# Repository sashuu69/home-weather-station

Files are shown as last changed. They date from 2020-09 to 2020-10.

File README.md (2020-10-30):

# Home Weather Station

## Introduction

The home Weather Station is a DIY weather Station that collects the following data and uploads the data to firebase:-

1. Air Quality Index
2. Compressed Natural Gas (CNG)
3. Liquid Petroleum Gas (LPG)
4. Smoke
5. Rain
6. Temperature
7. Humidity
8. Heat Index

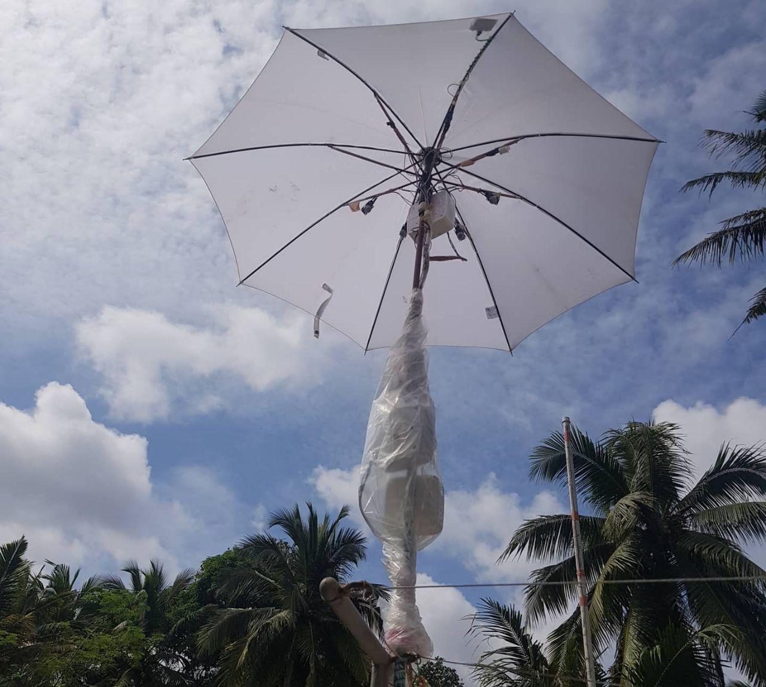
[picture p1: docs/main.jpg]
<br>

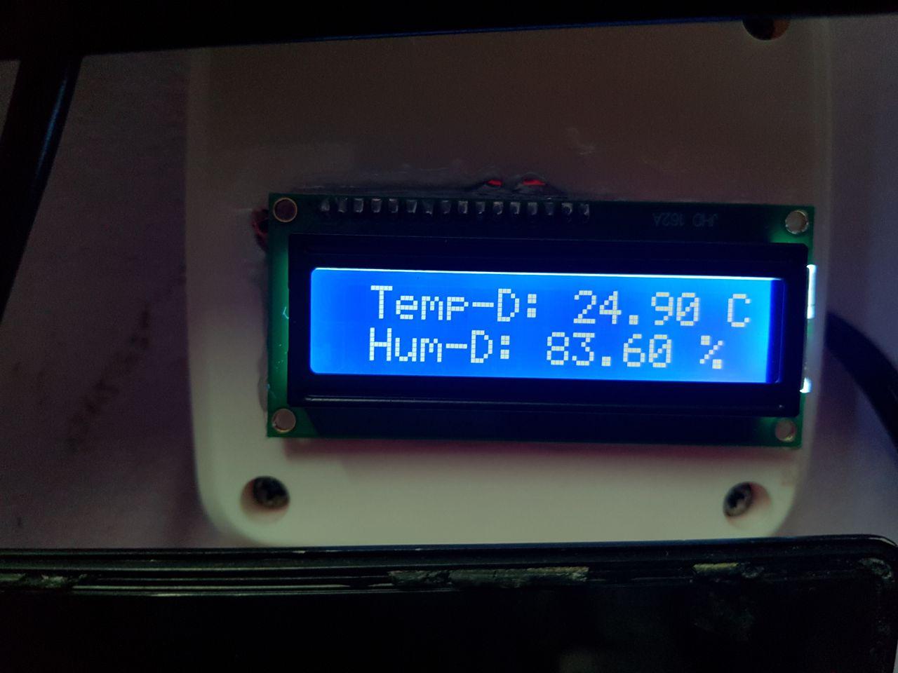
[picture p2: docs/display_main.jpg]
<br>

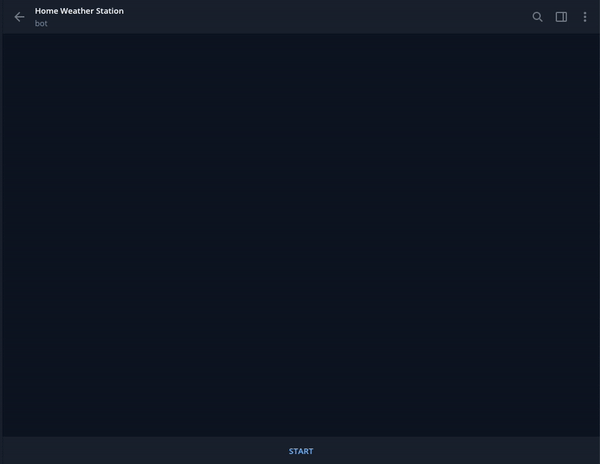
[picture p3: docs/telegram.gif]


## Features

1. Collects AQI, CNG, LPG, smoke, temperature, humidty, rain presence and heat index. The values from gas sensors are converted to PPM. Thank you for [Bharath Kinnera](https://www.youtube.com/channel/UCRqjLSpVN0EyjDmoq2dKJwg) for this [Gas sensor PPM conversion video](https://www.youtube.com/watch?v=w5kyyQCsyfQ).
2. Stores the data in a log file and Firebase.
3. Dispays the data in a LCD display.
4. A telegram bot for fetching values.

## Folder Structure

1. arduino_nano_code: Contains the embedded C code for flashing to the arduino nano board.
2. arduino_uno_code: Contains the embedded C code for flashing to the arduino uno board.
3. docs: Contains images of the product.
4. heroku_code/telegram-bot: Telegram bot python code for Heroku server.
    1. telebot
        1. __init__.py: Library initialisation.
    2. app.py: Main program for telegram bot.
    3. Procfile: Procfile is for Heruku.
    4. requirements.txt: Library names required for running telegram bot program.
5. pi_code: Contains the code to be run on the Raspberry Pi Zero W.
    1. dataRetriver.py: Python program that gets values from sensor and stores the data in log file and firebase.
    2. lcdDisplay.py: Python program to display data on LCD screen.
    3. requirements.txt: Required libraries for the python programs in this folder.
    4. RPi_I2C_driver.py: LCD display driver.
    5. sampleENV: A sample env that lists all the env variables used by the programs.

## Components Used

1. Arduino Nano - [Tomson Electronics](https://www.tomsonelectronics.com/products/buy-arduino-nano-v3-0-online-india)
2. Arduino UNO and programming cable - [Tomson Electronics](https://www.tomsonelectronics.com/products/arduino-bundle-1)
3. MQ-2 gas sensor - [Tomson Electronics](https://www.tomsonelectronics.com/products/mq-2-mq2-smoke-gas)
4. MQ-4 - [Amazon](https://www.amazon.in/REES52-Natural-Methane-Sensor-Arduino/dp/B01L0FIH94)
5. MQ-5 - [Tomson Electronics](https://www.tomsonelectronics.com/products/smoke-gas-detector-sensor-module)
6. MQ-135 - [Tomson Electronics](https://www.tomsonelectronics.com/products/air-quality-control-gas-sensor-mq-135)
7. Rain sensor - [Tomson Electronics](https://www.tomsonelectronics.com/products/rain-drop-detection-sensor-rain-detector-weather-module)
8. DHT22 - [Tomson Electronics](https://www.tomsonelectronics.com/products/dht22-digital-temperature-and-humidity-sensor-module-am2302)
9. Raspberry Pi Zero W - [Tomson Electronics](https://www.tomsonelectronics.com/products/buy-raspberry-pi-zero-w-online-india)
10. LCD module - [Tomson Electronics](https://www.tomsonelectronics.com/products/16x2-jhd-lcd-display)
11. LCD I2C module - [Tomson Electronics](https://www.tomsonelectronics.com/products/iic-i2c-serial-interface-adapter-module-for-display)
12. SD card class 10 16 GB - [Amazon](https://www.amazon.in/HP-MicroSD-U1-TF-Card-16GB/dp/B07DJGJ2H1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)
13. 220V to 12V DC Adapter - [Amazon](https://www.amazon.in/TRP-TRADERS-CAMCALL-Power-Adapter/dp/B01FTYAUCY)
14. Buck converter - [Tomson Electronics](https://www.tomsonelectronics.com/products/lm-2596-dc-dc-buck-converter)
15. Male headers - [Tomson Electronics](https://www.tomsonelectronics.com/products/40x2-male-berg-strip-straight)
16. Female headers - [Tomson Electronics](https://www.tomsonelectronics.com/products/40x2-female-berg-strip-straight)
17. Dotted PCB - [Robo Elements](https://www.roboelements.com/product/general-purpose-zero-pcb-printed-circuit-board-4x6-inches/)
18. Ribbon cable - [Amazon](https://www.amazon.in/Ribbon-Cable-10-wire-15ft/dp/B007R9SQQM)
19. USB extension cable - [Amazon](https://www.amazon.com/Monoprice-Extension-Repeater-PlayStation-Keyboard/dp/B004PLLA9U?th=1)
20. Powered USB hub - [Amazon](https://www.amazon.in/Protronix-Port-USB-Power-Adapter/dp/B00REX6DRK)
21. Pole, Umbrella, wires, tapes and zip ties

Discount code for Tomson Electronics : ZENOOFF2020

## Pre-Installation Steps

1. Connect the sensors as per circuit diagram.
2. Flash the nano and uno code respectively.
3. Clone the project in Raspberry Pi Zero W.
4. Rename sampleENV as .env.
5. Create Realtime database in firebase.
6. add the necessary edits to .env file
7. Run the python programs inside pi_code folder.
8. create a python inside heroku_code/telegram-bot with name credentials.py with following contents:-

    ```python
    bot_token = "Bot Token"
    bot_user_name = "Bot Username"
    URL = "Heroku app URL"
    firebase_token = "Firebase token"
    firebase_authDomain = "Firebase authDomain"
    firebase_databaseURL = "Firebase database URL"
    firebase_storageBucket = "Firebase Storage Bucket"
    ```

## Images

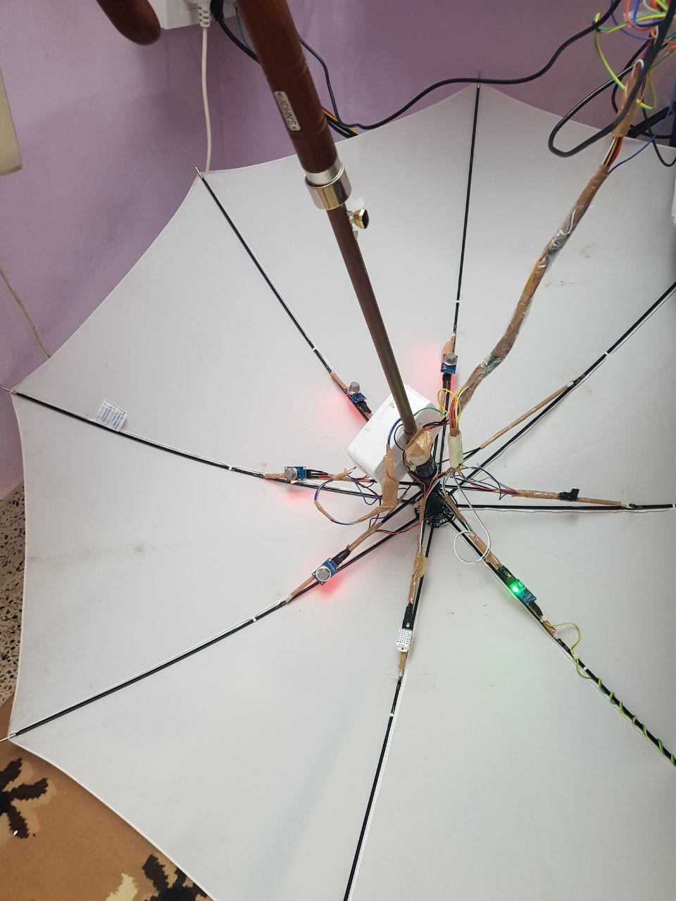
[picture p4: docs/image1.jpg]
<br>

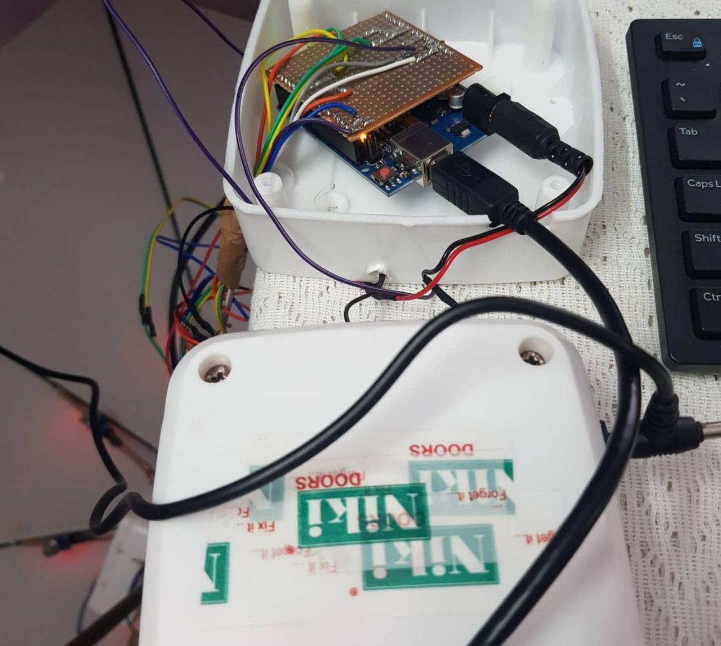
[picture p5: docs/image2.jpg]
<br>

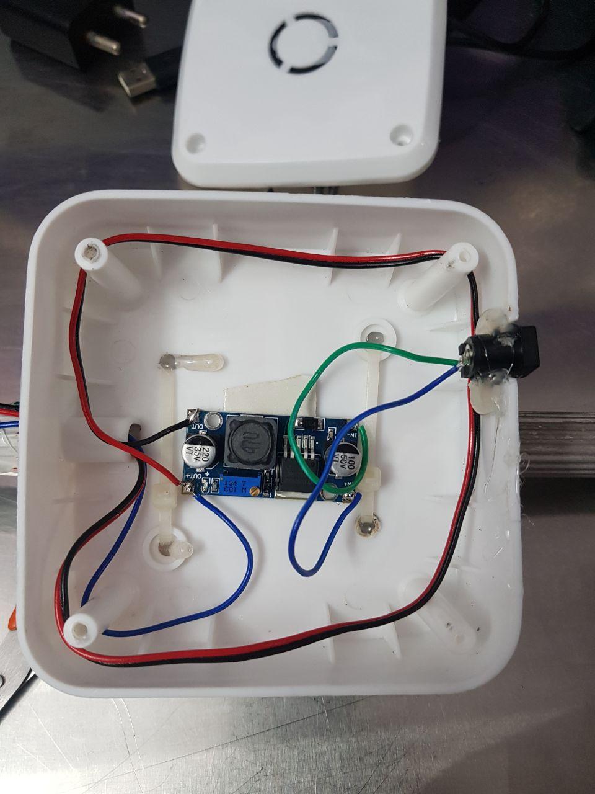
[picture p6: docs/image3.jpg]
<br>

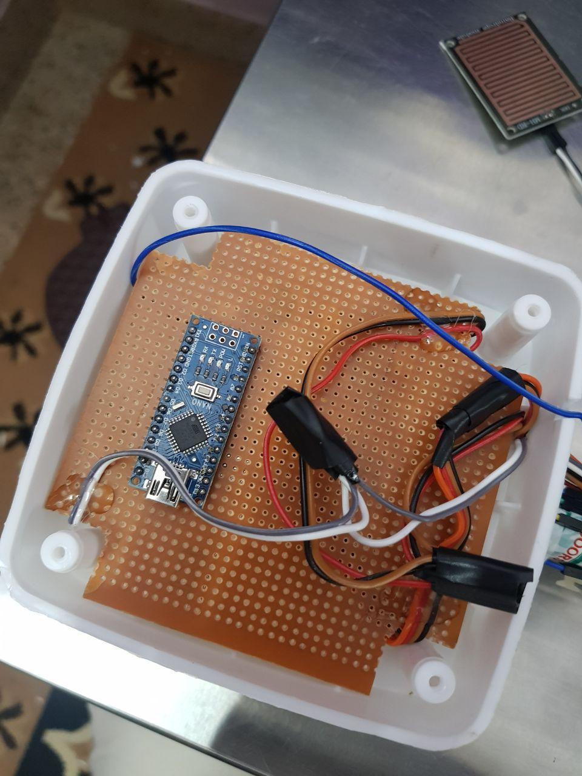
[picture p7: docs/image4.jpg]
<br>

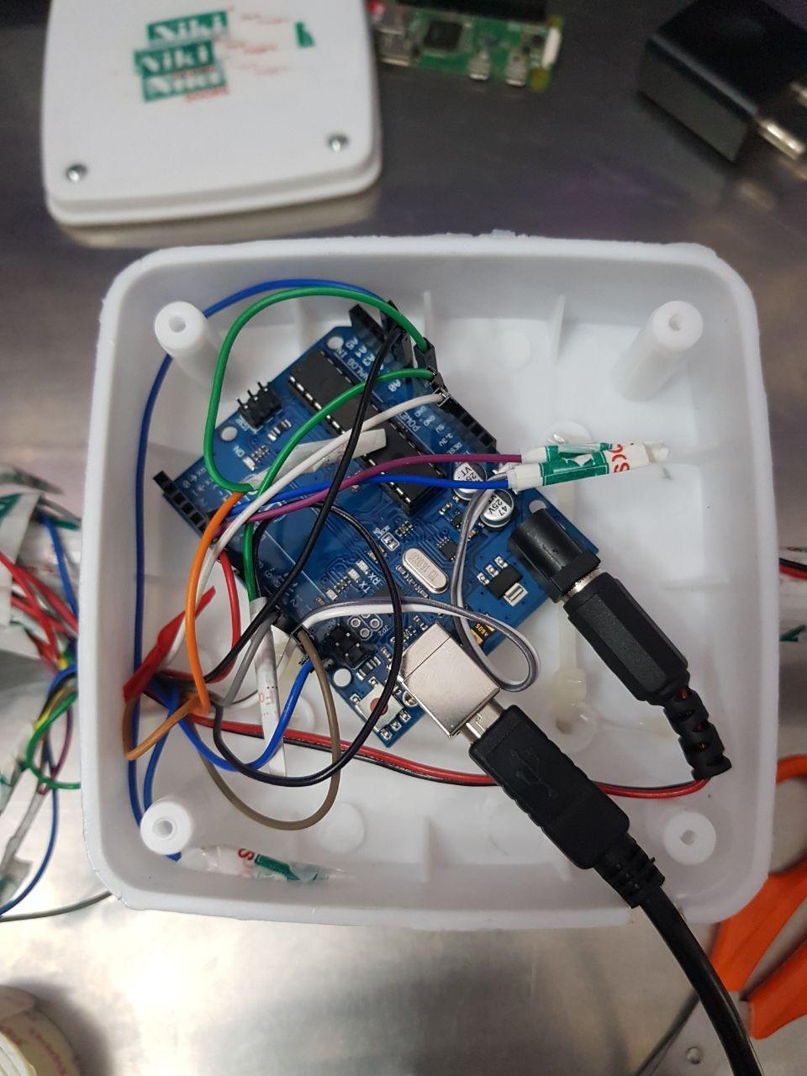
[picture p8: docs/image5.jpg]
<br>

## Sensor Info

Sensor Name  | Features
------------ | -------------
MQ-2 | Smoke
MQ-4 | CNG
MQ-5 | LPG
MQ-135 | AQI
Rain sensor | Rain
DHT22 | Temperature, Humidity and Heat Index

## Database

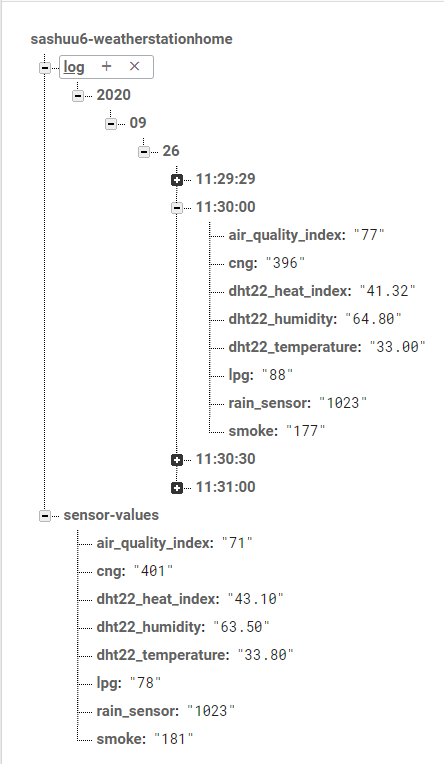
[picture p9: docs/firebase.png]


## Old Protoype

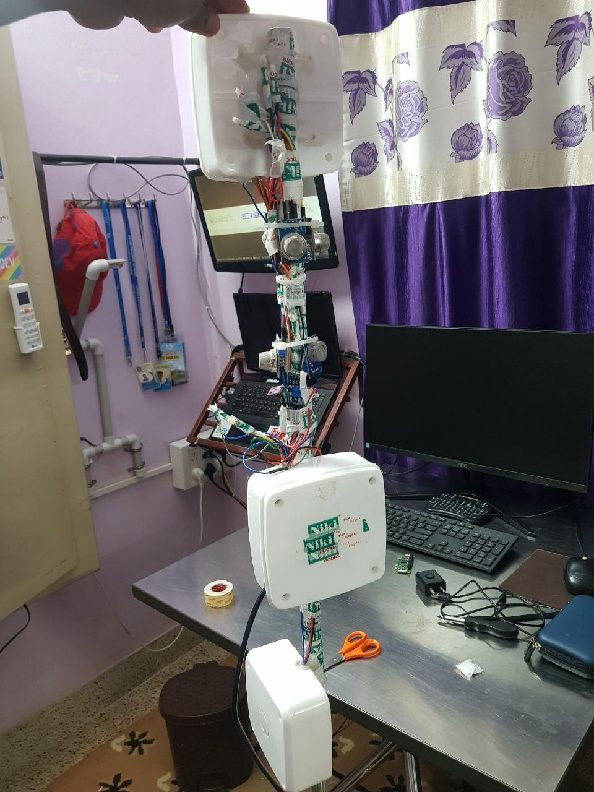
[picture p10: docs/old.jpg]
<br>

## Contributions

1. Sashwat K (@sashuu6) <sashwat0001@gmail.com>

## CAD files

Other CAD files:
fusion_design/Home Weather Station v1.f3d

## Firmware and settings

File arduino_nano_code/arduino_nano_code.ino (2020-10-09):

/*
 * Project Name : Home Weather Station
 * Purpose : To get values from MQ-4, MQ-135, MQ-5 and MQ-2 and send to UNO via software serial as PPM
 * Created on : 12 Sep 2020
 * Created by : Sashwat K <sashwat0001@gmail.com>
 * Revision : 4
 * Last Updated by : Sashwat K <sashwat0001@gmail.com> 
 * Last updated on : 09 Oct 2020
 */

#include <ArduinoJson.h> // Library for JSON

#include <SoftwareSerial.h> // Library for Software Serial

SoftwareSerial sSerialToUNO(6, 7); //RX, TX

const int mq4 = A0; // CNG gas
const int mq135 = A1; // Air Quality Index
const int mq5 = A2; // LPG gas
const int mq2 = A3; // Smoke

// For Gas sensors
float m = -0.6527; //Slope 
float b = 1.30; //Y-Intercept 
float R0 = 21.91; //Sensor Resistance in fresh air from previous code

void setup() {
  // put your setup code here, to run once:
  
  // Initialise sensors
  pinMode(mq4, INPUT); // MQ4 for CNG gas
  pinMode(mq135, INPUT); // MQ4 for Air Quality Index
  pinMode(mq5, INPUT); // MQ5 for LNG gas
  pinMode(mq2, INPUT); // MQ2 for smoke

  // Initialise Serial
  Serial.begin(9600);
  
  while (!Serial) continue; // Check if Serial is available or not
  
  sSerialToUNO.begin(4800); // Begin software Serial
}

void loop() {
  // put your main code here, to run repeatedly:

  // Get values from Sensor in PPM
  double mq4_value = analogToPPM(analogRead(mq4));
  double mq135_value = analogToPPM(analogRead(mq135));
  double mq5_value = analogToPPM(analogRead(mq5));
  double mq2_value = analogToPPM(analogRead(mq2));

  // Create JSON data
  StaticJsonDocument<200> doc;
  doc["cng_gas"] = mq4_value;
  doc["aqi_gas"] = mq135_value;
  doc["lpg_gas"] = mq5_value;
  doc["smoke_gas"] = mq2_value;
  serializeJson(doc, sSerialToUNO); // Send JSON via Serial

  // Display data for Debugging
  Serial.println("************************************");
  Serial.print("MQ-4 Value: ");Serial.print(mq4_value, DEC);Serial.println(" PPM");
  Serial.print("MQ-135 Value: ");Serial.print(mq135_value, DEC);Serial.println(" PPM");
  Serial.print("MQ-5 Value: ");Serial.print(mq5_value, DEC);Serial.println(" PPM");
  Serial.print("MQ-2 Value: ");Serial.print(mq2_value, DEC);Serial.println(" PPM");
  Serial.println("************************************\n\n");
  
  delay(30000); // 30 Seconds
}

// Function to convert analog values from gas sensors to PPM
double analogToPPM(int aValue) {
  float sensor_volt; //Define variable for sensor voltage 
  float RS_gas; //Define variable for sensor resistance  
  float ratio; //Define variable for ratio
  int sensorValue = aValue; //Read analog values of sensor

  sensor_volt = sensorValue*(5.0/1023.0); //Convert analog values to voltage 
  RS_gas = ((5.0*10.0)/sensor_volt)-10.0; //Get value of RS in a gas
  ratio = RS_gas/R0;  // Get ratio RS_gas/RS_air

  double ppm_log = (log10(ratio)-b)/m; //Get ppm value in linear scale according to the the ratio value  

  return ppm_log;
}

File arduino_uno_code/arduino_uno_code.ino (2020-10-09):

/*
 * Project Name : Home Weather Station
 * Purpose : To get values from MQ-4, MQ-135, MQ-5 and MQ-2 and send to UNO via software serial
 * Created on : 12 Sep 2020
 * Created by : Sashwat K <sashwat0001@gmail.com>
 * Revision : 4
 * Last Updated by : Sashwat K <sashwat0001@gmail.com> 
 * Last updated on : 09 Oct 2020
 */

#include <ArduinoJson.h> // Library for JSON

#include <SoftwareSerial.h> // Library for Software Serial

#include "DHT.h" // Library for DHT22
#define DHTPIN 8
#define DHTTYPE DHT22

SoftwareSerial sSerialToNano(6, 7); // Software Serial with Nano (RX,TX)

DHT dht(DHTPIN, DHTTYPE); // Initialise DHT22

const int rainSensorPin = A0; // Rain sensor pin

void setup() {
  // put your setup code here, to run once:
  
  // Initialise sensors
  pinMode(rainSensorPin, INPUT);
  
  dht.begin();
  
  // Initialise Serial
  Serial.begin(9600);
  
  while (!Serial) continue;
  
  sSerialToNano.begin(4800);
}

void loop() {
  // put your main code here, to run repeatedly:
  
  int rainSensor_value = analogRead(rainSensorPin);
  float dhtTemp = dht.readTemperature();
  float dhtHum = dht.readHumidity();
  float heatIndex = dht.computeHeatIndex(dhtTemp, dhtHum, false);
  
  if (sSerialToNano.available()) {
    
    StaticJsonDocument<400> doc;
    
    // Read the JSON document from the "link" serial port
    DeserializationError err = deserializeJson(doc, sSerialToNano);
    
    if (err == DeserializationError::Ok) {
      
      double cngGas = doc["cng_gas"].as<double>();
      double apiGas = doc["aqi_gas"].as<double>();
      double lpgGas = doc["lpg_gas"].as<double>();
      double smokeGas = doc["smoke_gas"].as<double>();
      
      String finalValue;
      
      // CNG, AQI, LPG, Smoke, Rain sensor, DHT Temperature, DHT Humidity, DHT HI
      finalValue = String(cngGas?cngGas:0) + "," + String(apiGas?apiGas:0) + "," + String(lpgGas?lpgGas:0) + "," + String(smokeGas?smokeGas:0) + "," + String(rainSensor_value?rainSensor_value:0) + "," + String(dhtTemp?dhtTemp:0) + "," + String(dhtHum?dhtHum:0) + "," + String(heatIndex?heatIndex:0);
      Serial.println(finalValue);
    }
    else {
      
      // Print error to the "debug" serial port
      Serial.print("deserializeJson() returned ");
      Serial.println(err.c_str());
  
      // Flush all bytes in the "link" serial port buffer
      while (sSerialToNano.available() > 0)
        sSerialToNano.read();
    }
  }
}

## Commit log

2020-09-12 Made some documentation and fixed JSON error
    [arduino_nano_code.ino]
2020-09-13 Added new code for arduino uno and nano
2020-09-26 Removed support for BMP sensor and MQ-7 sensor
2020-10-04 Added PPM support for gas sensor
2020-10-06 Added new fritzing design
    [home-weather-station.fzz]
2020-10-06 Added fusion design
    [Home Weather Station v1.f3d]
2020-10-09 Fixed all errors
    [Home Weather Station v1.f3d]
2020-10-30 Removed fritzing, eagle design. Edited README
    [home-weather-station.fzz]
